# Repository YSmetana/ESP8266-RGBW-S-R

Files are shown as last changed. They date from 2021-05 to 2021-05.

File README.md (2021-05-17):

View this project on [CADLAB.io](https://cadlab.io/project/24310). 

# ESP8266-RGBW-S-R

**ESP8266**-based **RGBW** controller with **S**ensor and **R**elay support.

This harware design (PCB) is based on the [ESP-GO project and Hackitt & Bodgitt board](https://tech.scargill.net/home-control-2018/) created by [Pete Scargill](https://tech.scargill.net/) and [Aidan Ruff](https://www.scargill.net/cv/).

## PCB
96x55 mm.
### Render
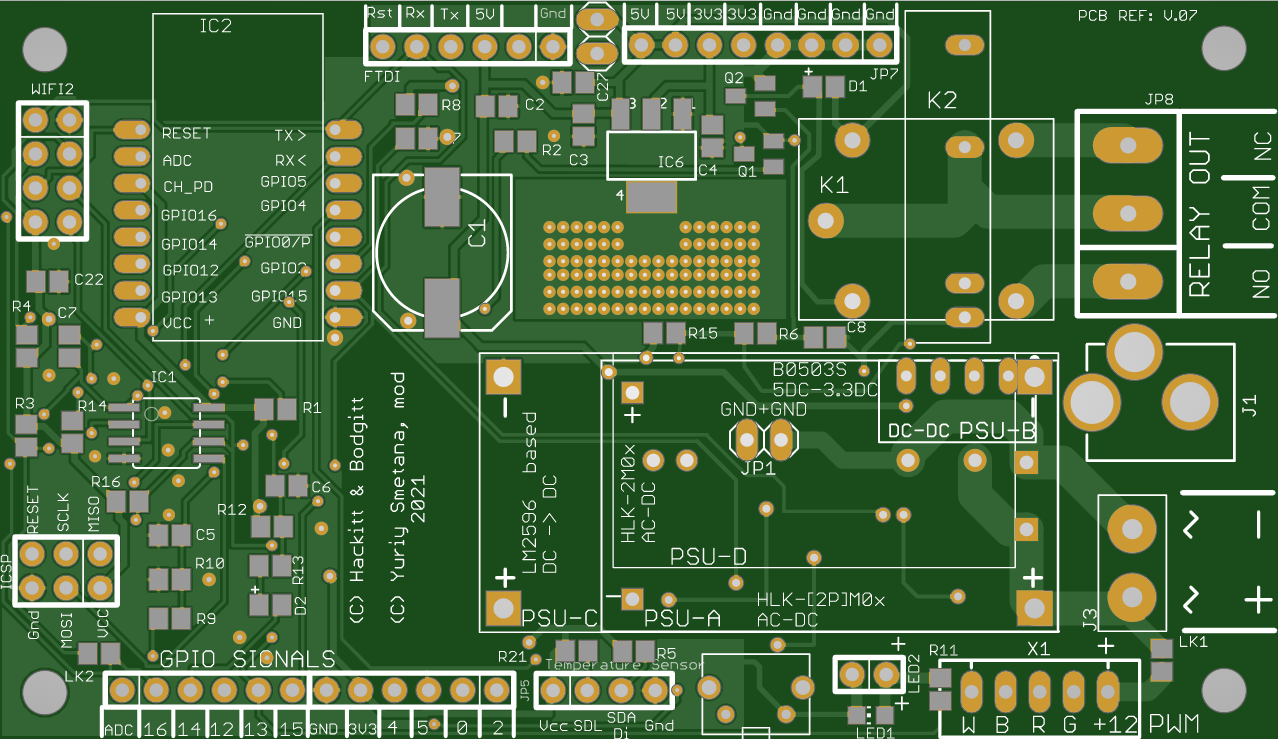
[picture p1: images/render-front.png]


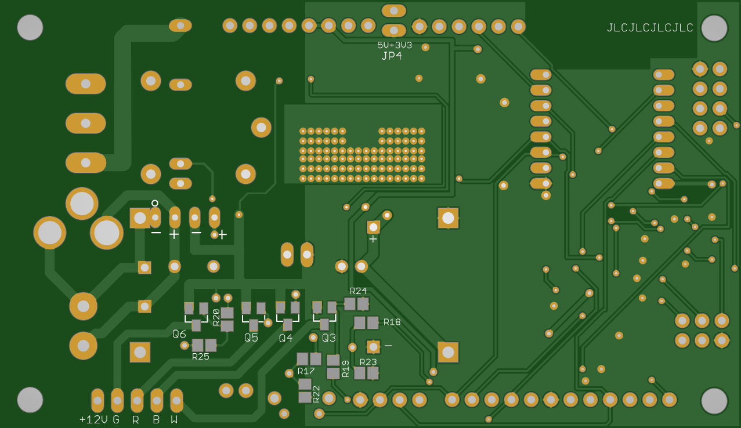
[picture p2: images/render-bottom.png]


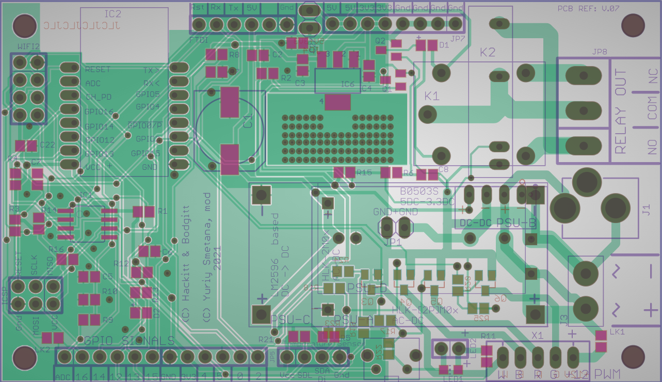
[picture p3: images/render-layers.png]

### Actual photos
## Power supply
AC 110-220V or DC 5V, DC 5-24V.

### AC 110-220V, 5V needed
Use **PSU-A** HLK-PM01, output DC 5V. DC 3.3V via onboard LM1117-3.3.

### AC 110-220V, NO 5V needed
Use **PSU-D** HLK-2M03, output DC 3.3V. Short J4 to supply 3.3V directly from DC-DC convertor.

### DC 5V
Use **PSU-B** B0503S, output DC 3.3V. No onboard 3.3 regulator needed. Short J4 to supply 3.3V directly from DC-DC convertor.

### DC 5-24V
Use **PSU-C** LM2596-based buck convertor. Set output to 5V and use onboard LM1117-3.3. Or set output to 3.3V and short **J4** to supply 3.3V directly from DC-DC convertor.

## Errors found

In version **0.7** I was trying to use pull-down resistors for PWM output pins, but it turned out that ESP can not start if TX (GPIO1) pin is pulled low during the boot. So please just **remove R25** (don't solder it). PWM works fine without it (and probably without R22-R24 too :) ), and it was not in the original version.

I did not use R8 (remove) either because it seems it is duplicated by R11.

Apparently, GPIO4 and GPIO5 are misplaced on the schematic (correct on the PCB footprint).

## Soldering

### Basic

#### SMD
* LK2 - just short it if you use LED strip and use input power for them.
* R3
* R4
* R5
* R7
* R10
* R11
* R16
* R12
* C5
* C6
* ESP (sometimes better to solder manually to avoid shotage under the ESP)

If using non 3.3V input and need on-board linear converter:
* C2
* C3
* C4
* C22
* C27
* IC6

Short JP4 **only if you have 3.3V input** already and do not need any extra converters. Input 5V line will be directly connected with internal 3.3V line.

#### THT
* C1 (not nessecery with a good DC-DC converter with capacitor on-board)
* LED2 (status)
* X1 (for PWM RGBW) 
* JP10 (for programming)
* PSU (check voltage on regulated converters). See «Power supply» section above.

## Temp/Humidity sensor, IC2
### SMD
* R21

## PWM RGBW (3A/ch max)
### SMD
* R22
* R23
* R24
* R17
* R18
* R19
* R20
* Q3
* Q4
* Q5
* Q6

## Relay
Have not tested. Solder according to schematic.

## Programming
I did not use ATtiny85. To switch ESP to programming mode short pins **2** (PROG) and **6** (GND) on **JP3**.


## License

Shield: [][cc-by-sa]

This work is licensed under a
[Creative Commons Attribution-ShareAlike 4.0 International License][cc-by-sa].

[][cc-by-sa]

[cc-by-sa]: http://creativecommons.org/licenses/by-sa/4.0/
[cc-by-sa-image]: https://licensebuttons.net/l/by-sa/4.0/88x31.png
[cc-by-sa-shield]: https://img.shields.io/badge/License-CC%20BY--SA%204.0-lightgrey.svg

## Disclaimer

THIS HARDWARE AND/OR SOFTWARE IS PROVIDED BY THE COPYRIGHT HOLDERS AND CONTRIBUTORS “AS IS” AND ANY EXPRESS OR IMPLIED WARRANTIES, INCLUDING, BUT NOT LIMITED TO, THE IMPLIED WARRANTIES OF MERCHANTABILITY AND FITNESS FOR A PARTICULAR PURPOSE ARE DISCLAIMED. IN NO EVENT SHALL THE COPYRIGHT OWNER OR CONTRIBUTORS BE LIABLE FOR ANY DIRECT, INDIRECT, INCIDENTAL, SPECIAL, EXEMPLARY, OR CONSEQUENTIAL DAMAGES (INCLUDING, BUT NOT LIMITED TO, PROCUREMENT OF SUBSTITUTE GOODS OR SERVICES; LOSS OF USE, DATA, OR PROFITS; OR BUSINESS INTERRUPTION) HOWEVER CAUSED AND ON ANY THEORY OF LIABILITY, WHETHER IN CONTRACT, STRICT LIABILITY, OR TORT (INCLUDING NEGLIGENCE OR OTHERWISE) ARISING IN ANY WAY OUT OF THE USE OF THIS SOFTWARE, EVEN IF ADVISED OF THE POSSIBILITY OF SUCH DAMAGE.

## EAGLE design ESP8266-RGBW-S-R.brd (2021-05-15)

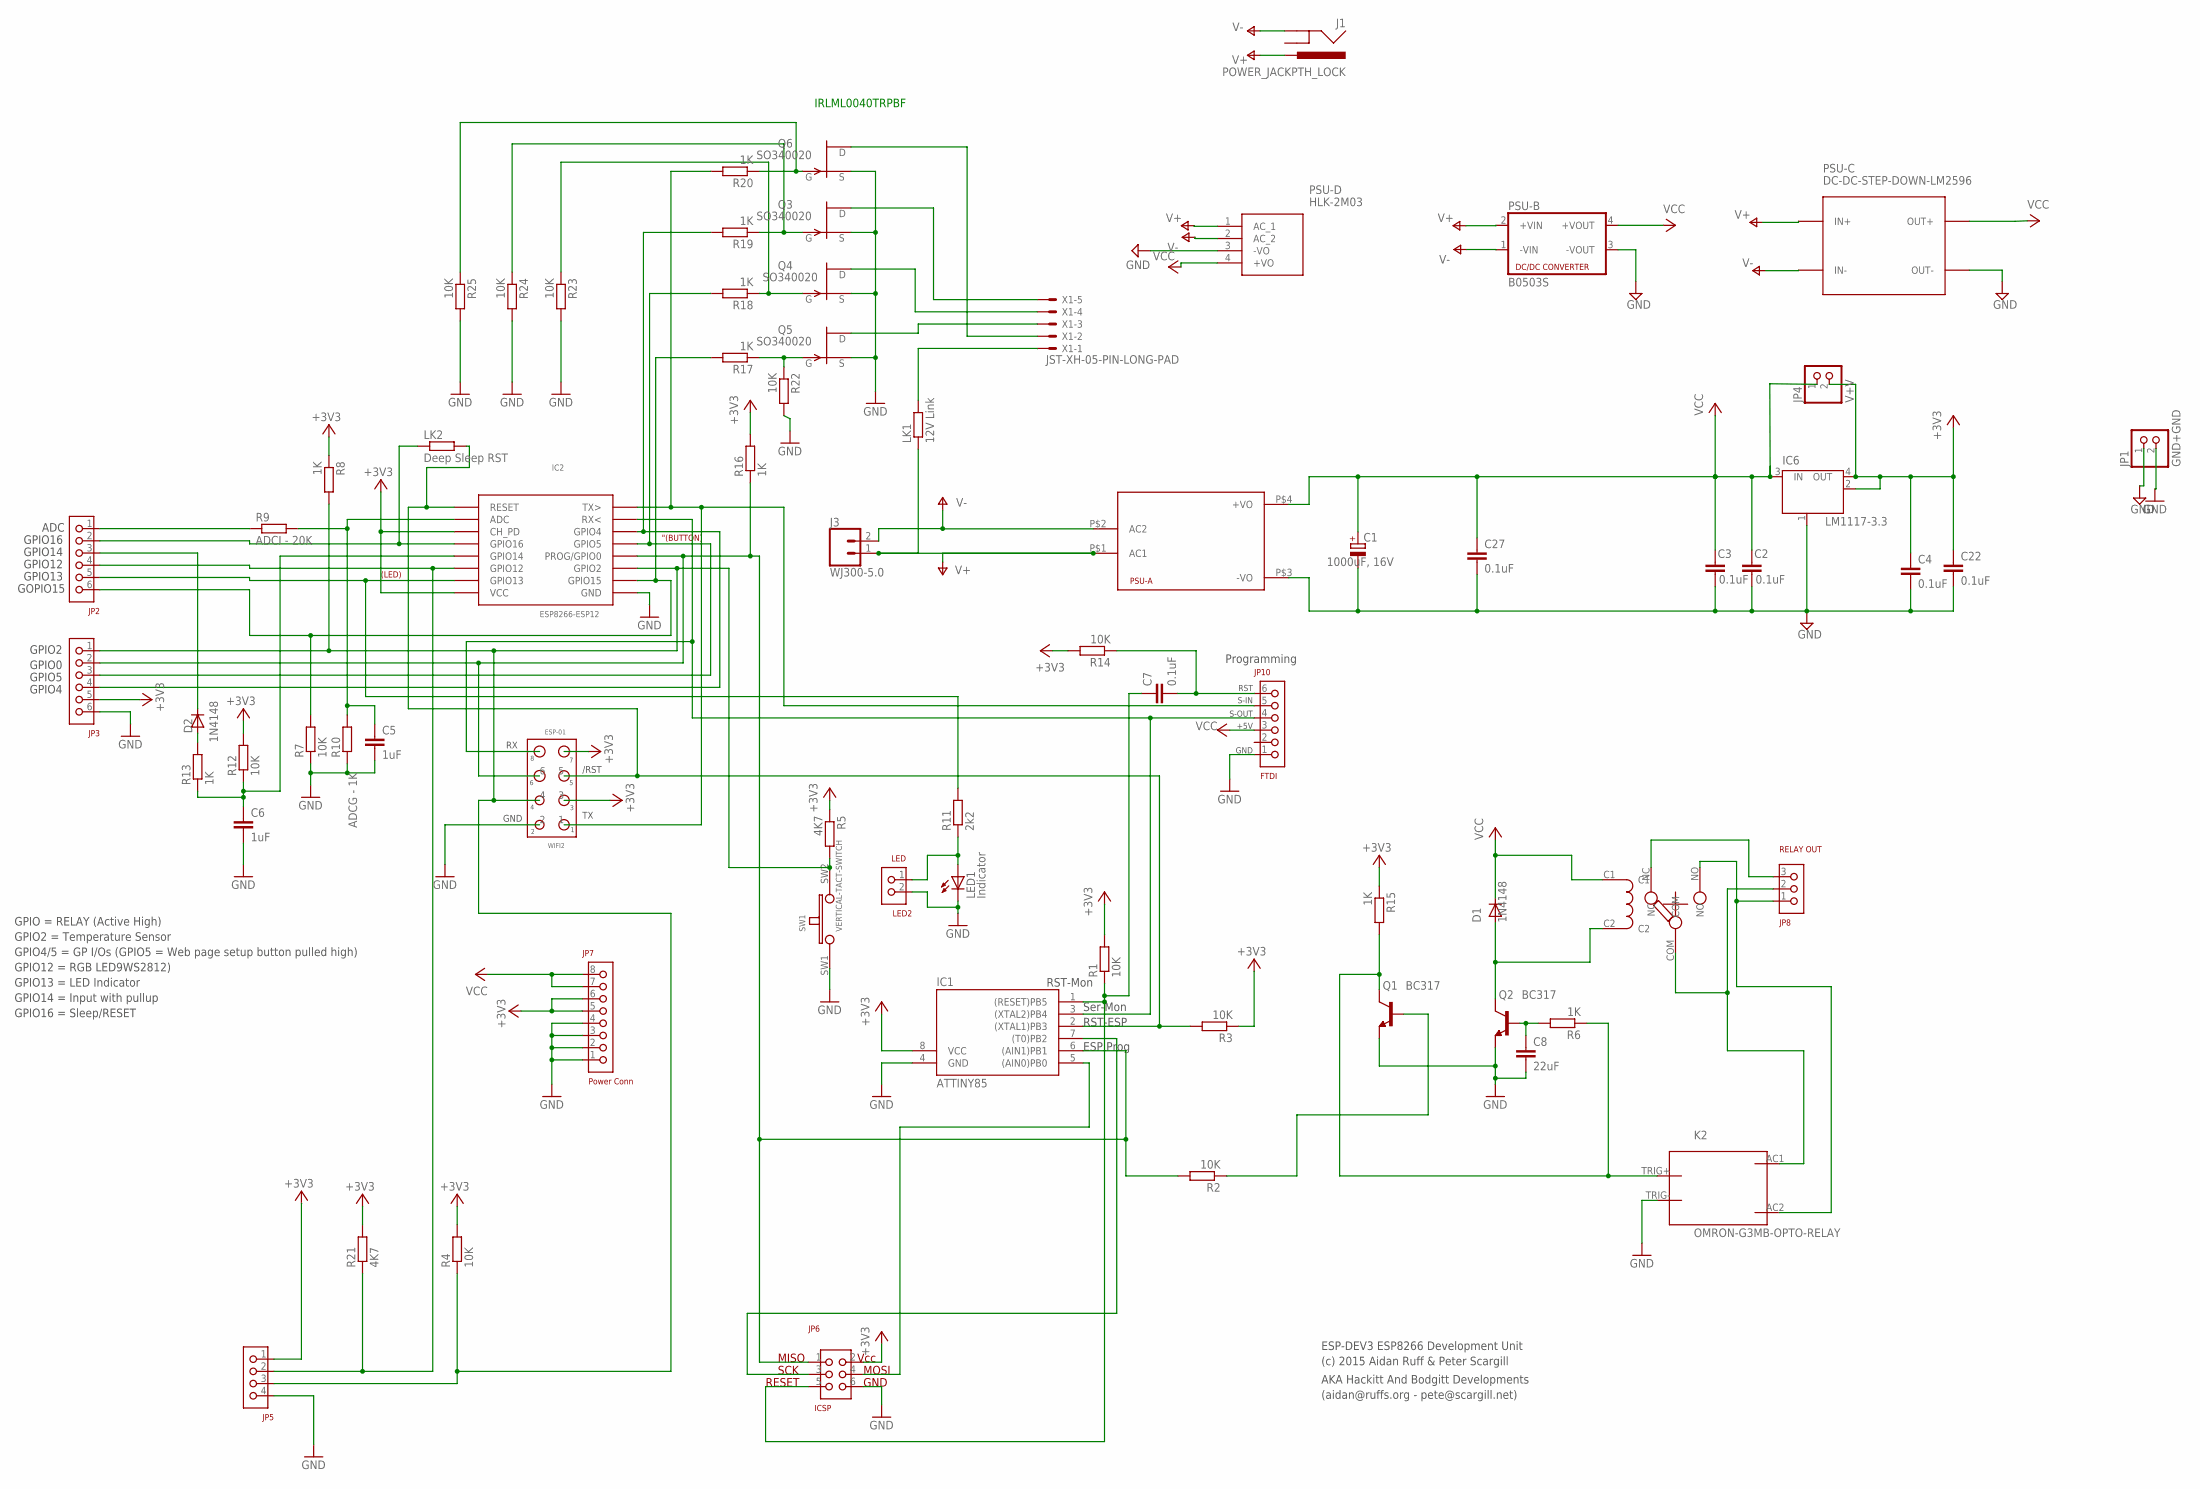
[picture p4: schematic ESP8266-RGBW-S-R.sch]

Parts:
C1: 1000uF, 16V; 150CLZ-1010
C2, C3, C4, C7, C22, C27: 0.1uF; C0805
C5, C6: 1uF; C0805
C8: 22uF; C0805
D1, D2: 1N4148; D0805
IC1: ATTINY85; SOIC8
IC2: ESP8266-ESP12; ESP8266-ESP12A
IC6: LM1117-3.3; SOT223
J1: POWER_JACKPTH_LOCK; POWER_JACK_PTH_LOCK
J3: WJ300-5.0; 1X02_XTRA_BIG
JP1: GND+GND; 1X02
JP2, JP3: HDR6X0.1
JP4: V+V; 1X02
JP5: HDR4X0.1
JP6: ICSP; HDR3X2X0.1
JP7: Power Conn; HDR8X0.1
JP8: RELAY OUT; 3X0.2
JP10: FTDI; HDR6X0.1
K1: SONGLE-RELAY-SPDT
K2: OMRON-G3MB-OPTO-RELAY
LED1: Indicator; CHIP-LED0805
LED2: LED; HDR2X0.1
LK1: 12V Link; R0805
LK2: Deep Sleep RST; R0805
PSU-A: HLK-PM013W; HLK-PM01
PSU-B: B0503S; NME
PSU-C: DC-DC-STEP-DOWN-LM2596
PSU-D: HLK-2M03; HLK2M03
Q1, Q2: BC317; SOT23-BEC
Q3, Q4, Q5, Q6: SO340020; SOT23
R1, R2, R3, R4, R7, R12, R14, R22, R23, R24, R25: 10K; R0805
R5, R21: 4K7; R0805
R6, R8, R13, R15, R16, R17, R18, R19, R20: 1K; R0805
R9: ADCI - 20K; R0805
R10: ADCG - 1K; R0805
R11: 2k2; R0805
SW1: VERTICAL-TACT-SWITCH
WIFI2: ESP-01; 4X2X0.1
X1: JST-XH-05-PIN-LONG-PAD; JST-XH-05-PACKAGE-LONG-PAD

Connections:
+3V3: C4.1, C22.1, IC1.8 (VCC), IC2.CH_PD, IC2.VCC, IC6.2 (OUT), IC6.4 (OUT), JP3.5, JP4.2, JP5.1, JP6.2, JP7.5, JP7.6, R1.2, R3.1, R4.2, R5.1, R8.1, R12.2, R14.2, R15.1, R16.2, R21.2, WIFI2.3, WIFI2.7
+VCC: C1.+, C2.1, C3.1, C27.1, D1.C, IC6.3 (IN), JP4.1, JP7.7, JP7.8, JP10.3, K1.C1, PSU-A.P$4 (+VO)
ADC: JP2.1, R9.1
GND: C1.-, C2.2, C3.2, C4.2, C5.2, C6.2, C8.2, C22.2, C27.2, IC1.4 (GND), IC2.GND, IC6.1 (GND/ADJ), JP1.1, JP1.2, JP3.6, JP5.4, JP6.6, JP7.1, JP7.2, JP7.3, JP7.4, JP10.1, K2.TRIG-, LED1.C, LED2.2, PSU-A.P$3 (-VO), PSU-B.3 (-VOUT), PSU-C.OUT-, PSU-D.3 (-VO), Q1.E, Q2.E, Q3.2 (S), Q4.2 (S), Q5.2 (S), Q6.2 (S), R7.1, R10.1, R22.2, R23.2, R24.2, R25.2, SW1.SW1, WIFI2.2
GPIO0: IC1.6 ((AIN1)PB1), IC2.PROG/GPIO0, JP3.2, JP6.1, R2.2, R16.1, WIFI2.6
GPIO2: IC2.GPIO2, JP3.1, JP5.3, R4.1, R5.2, R8.2, SW1.SW2, WIFI2.4
GPIO3: IC2.TXD (TX>), JP10.5, R20.2, WIFI2.1
GPIO4: IC2.GPIO4, JP3.4, R19.2
GPIO5: IC2.GPIO5, JP3.3, R18.2
GPIO13: IC2.GPIO13, JP2.5, R11.2
GPIO15: IC2.GPIO15, JP2.6, R7.2, R17.2
GPIO16: IC1.2 ((XTAL1)PB3), IC2.RESET, LK2.2, R3.2, WIFI2.5
MOSI: IC1.5 ((AIN0)PB0), JP6.4
unnamed: K2.TRIG+, Q1.C, R6.1, R15.2
unnamed: C5.1, IC2.ADC, R9.2, R10.2
unnamed: LED1.A, LED2.1, R11.1
unnamed: C6.1, IC2.GPIO14, R12.1, R13.1
unnamed: D2.A, R13.2
unnamed: IC1.3 ((XTAL2)PB4), IC2.RXD (RX<), JP10.4, WIFI2.8
unnamed: D2.C, JP2.3
unnamed: C7.2, JP10.6, R14.1
unnamed: IC2.GPIO12, JP2.4, JP5.2, R21.1
unnamed: Q6.3 (D), X1.2
unnamed: Q1.B, R2.1
unnamed: Q5.3 (D), X1.3
unnamed: JP8.2, K1.COM, K2.AC1
unnamed: JP8.1, K1.NO, K2.AC2
unnamed: JP8.3, K1.NC
unnamed: D1.A, K1.C2, Q2.C
unnamed: C8.1, Q2.B, R6.2
unnamed: Q4.3 (D), X1.4
unnamed: LK1.2, X1.1
unnamed: Q5.1 (G), R17.1, R22.1
unnamed: Q4.1 (G), R18.1, R23.1
unnamed: Q3.1 (G), R19.1, R24.1
unnamed: IC2.GPIO16, JP2.2, LK2.1
unnamed: Q3.3 (D), X1.5
unnamed: Q6.1 (G), R20.1, R25.1
RESET: C7.1, IC1.1 ((RESET)PB5), JP6.5, R1.1
SCLK: IC1.7 ((T0)PB2), JP6.3
V+: J1.PWR, J3.1, LK1.1, PSU-A.P$1 (AC1), PSU-B.2 (+VIN), PSU-C.IN+, PSU-D.1 (AC_1)
V-: J1.GND, J3.2, PSU-A.P$2 (AC2), PSU-B.1 (-VIN), PSU-C.IN-, PSU-D.2 (AC_2)
VCC: PSU-B.4 (+VOUT), PSU-C.OUT+, PSU-D.4 (+VO)

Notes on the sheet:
Programming
RST
S-IN
S-OUT
+5V
GND
/RST
RST-ESP
Ser-Mon
RST-Mon
ESP Prog
MISO
SCK
RESET
MOSI
Vcc
(LED)
"(BUTTON)
GPIO = RELAY (Active High)
GPIO2 = Temperature Sensor
GPIO4/5 = GP I/Os (GPIO5 = Web page setup button pulled high)
GPIO12 = RGB LED9WS2812)
GPIO13 = LED Indicator
GPIO14 = Input with pullup
GPIO16 = Sleep/RESET
ADC
GPIO16
GPIO14
GPIO12
GPIO13
GOPIO15
GPIO2
GPIO0
GPIO5
GPIO4
ESP-DEV3 ESP8266 Development Unit
AKA Hackitt And Bodgitt Developments
(c) 2015 Aidan Ruff & Peter Scargill
(aidan@ruffs.org - pete@scargill.net)
IRLML0040TRPBF

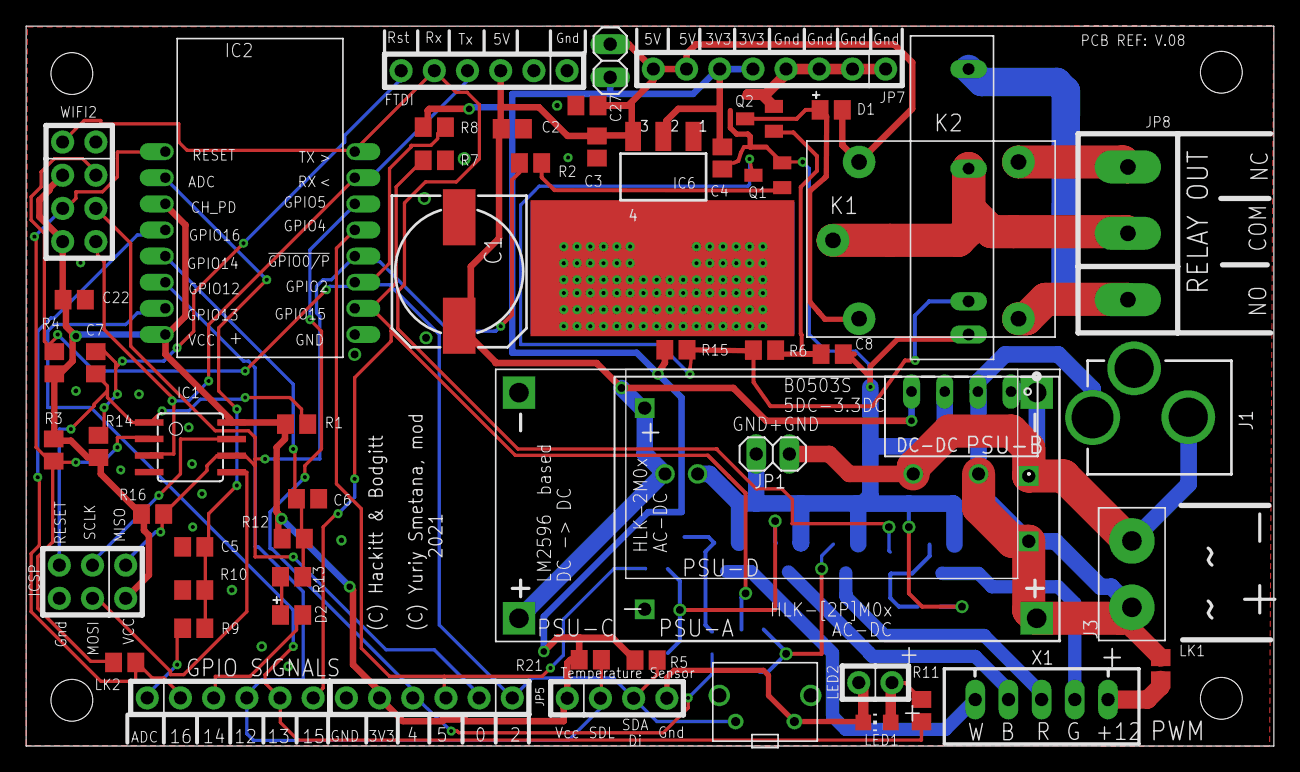
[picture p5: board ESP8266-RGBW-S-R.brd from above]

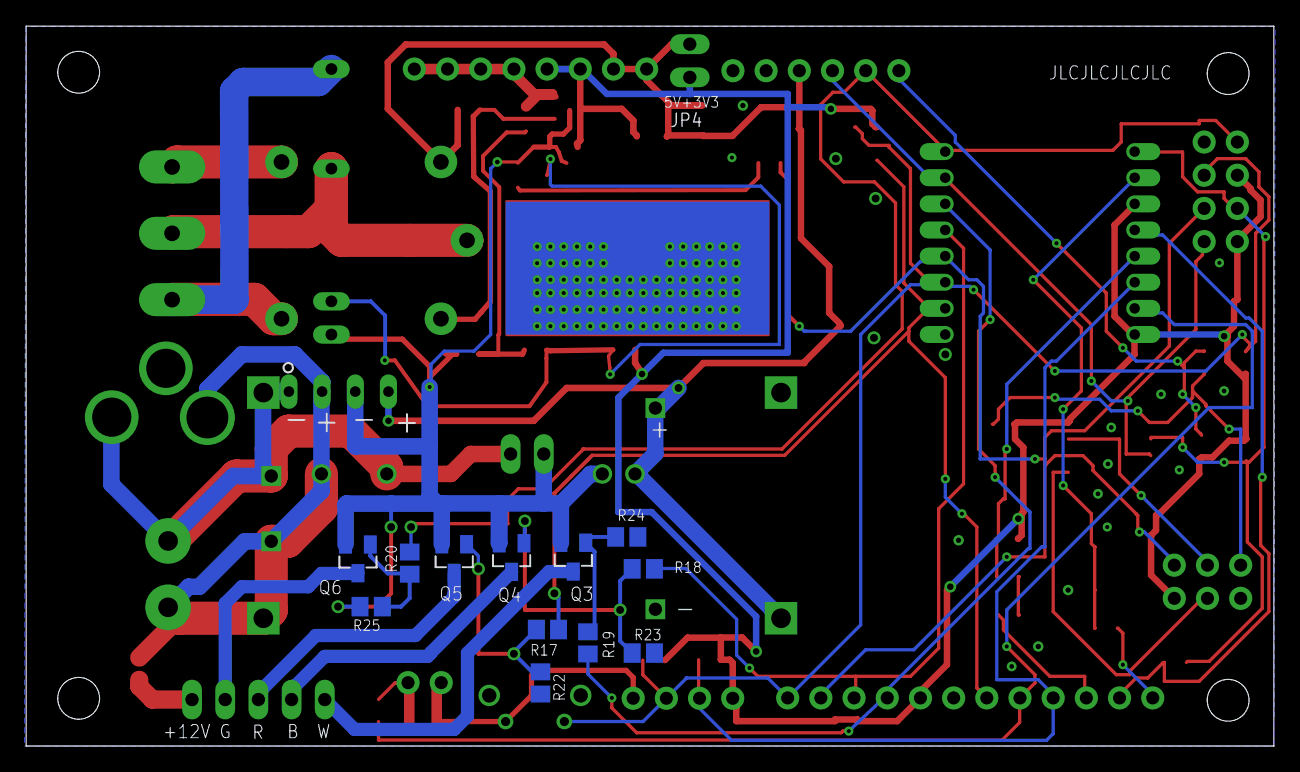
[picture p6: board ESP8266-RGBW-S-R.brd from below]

Board: 2 copper layers, 95.5 x 55.1 mm, 70 parts (12 on the bottom side), 43 nets.

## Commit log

2021-05-15 original schematic and PCB from ESP-GO project and Hackitt & Bodgitt board created by Pete Scargill and Aidan Ruff
    [ESP8266-RGBW-S-R.brd, ESP8266-RGBW-S-R.sch]
2021-05-15 added White channel for PWM output
    [ESP8266-RGBW-S-R.brd, ESP8266-RGBW-S-R.sch]
2021-05-15 alternative power subbly (DC-DC, AC-DC), alternative power jack as input
    [ESP8266-RGBW-S-R.brd, ESP8266-RGBW-S-R.sch]
2021-05-15 v 0.6
    [ESP8266-RGBW-S-R.brd, ESP8266-RGBW-S-R.sch]
2021-05-15 pull down resistors for the PWM control, some silkprint correction
    [ESP8266-RGBW-S-R.brd, ESP8266-RGBW-S-R.sch]
2021-05-15 Gerber files
    [copper_bottom.gbr, copper_top.gbr, gerber_job.gbrjob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]
2021-05-15 r11 moved
    [ESP8266-RGBW-S-R.brd]
2021-05-15 power supplies options

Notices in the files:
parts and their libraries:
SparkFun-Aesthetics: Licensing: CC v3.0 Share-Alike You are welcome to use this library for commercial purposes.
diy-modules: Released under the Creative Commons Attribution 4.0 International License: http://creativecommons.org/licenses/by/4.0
